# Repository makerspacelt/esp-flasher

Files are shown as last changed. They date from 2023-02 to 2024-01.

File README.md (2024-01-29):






---
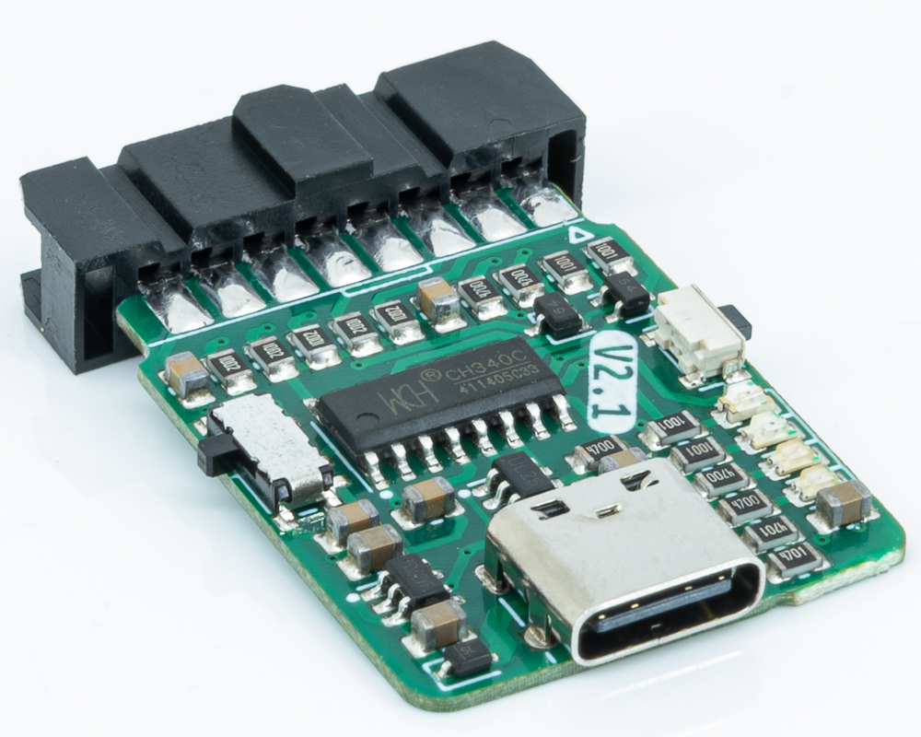
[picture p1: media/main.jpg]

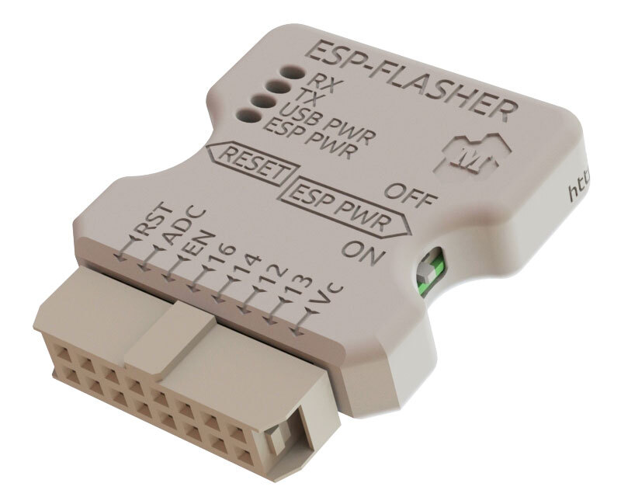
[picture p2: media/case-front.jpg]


This is ESP8266 modular flasher based on CH340 usb uart converter and USB-C port.

* Flashing works with standard `esptool`
* Device can reset ESP automatically
* Device can enter into ESP flashing mode automatically

Support this open-source project - buy your fully assembled and tested flasher [here](http://esp-flasher.makerspace.lt/shop)

For programming and debugging without any onboard provisions in-place use one of these interfaces:

* [ESP-12F interface module](http://esp-12f.makerspace.lt/repo)
* [ESP-01 interface module](http://esp-01.makerspace.lt/repo)

Dev NOTE: before commit, run `./kibot.sh` to regenerate documentation, bom, gerbers and other assets.

* [schematics.pdf](gen/schematics.pdf)
* [pcb.pdf with dimensions](gen/pcb.pdf)
* [ibom.html](gen/single/ibom.html)

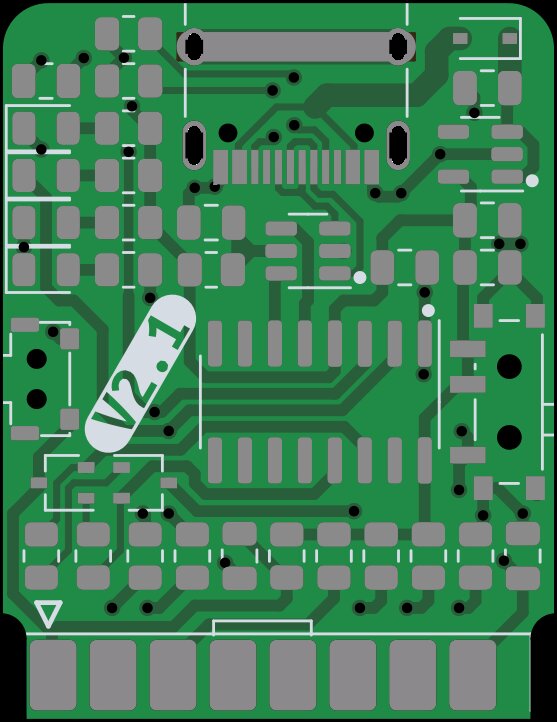
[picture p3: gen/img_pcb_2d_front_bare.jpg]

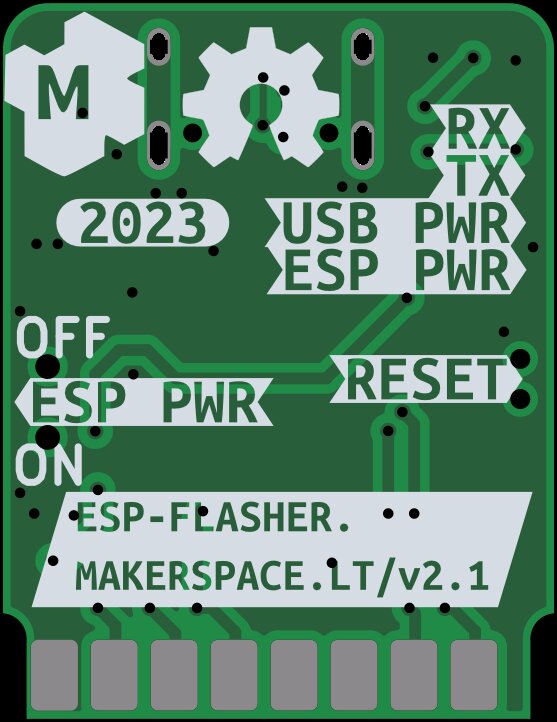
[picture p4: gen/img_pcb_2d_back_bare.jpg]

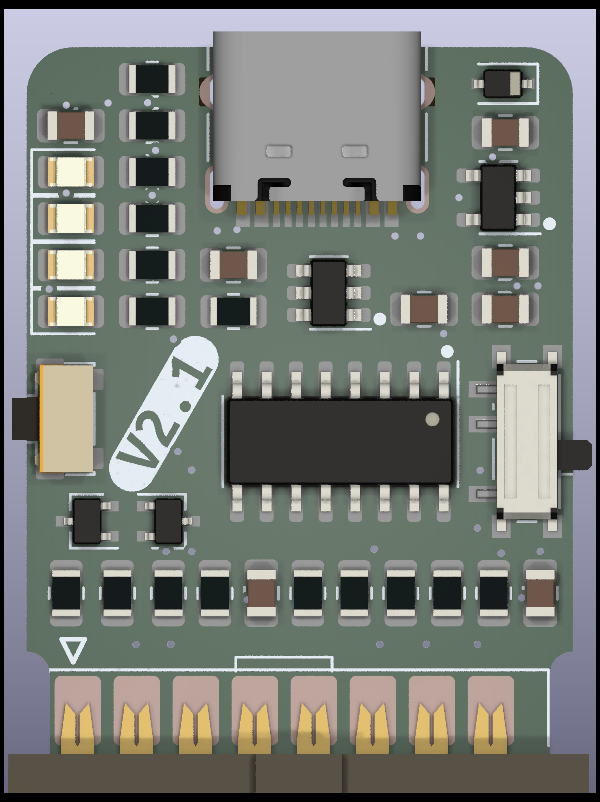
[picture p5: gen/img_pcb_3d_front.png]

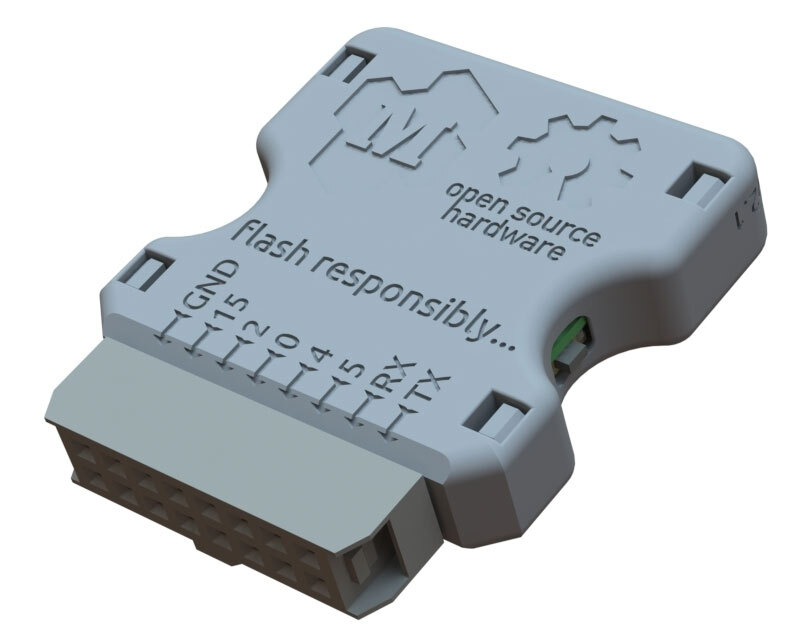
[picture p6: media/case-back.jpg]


---

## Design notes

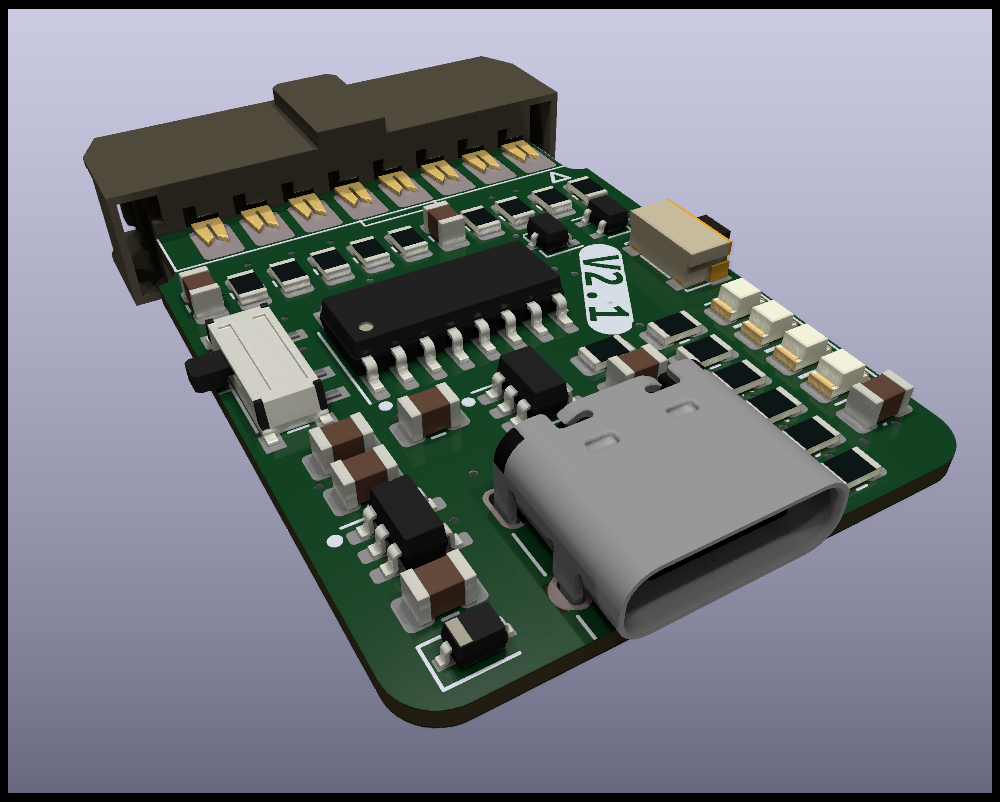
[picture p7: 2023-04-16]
gen/img_pcb_3d_main.png

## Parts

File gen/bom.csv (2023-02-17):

Row | Description | Part | References | Value | Footprint | Quantity Per PCB | Status | Datasheet | jlc-part-type | lcsc# | mpn
1 | Unpolarized capacitor | C | C1,C3,C5,C7,C8 | 100n | C_0805_2012Metric | 5 |  | ~ | B | C28233
2 | Unpolarized capacitor | C | C2,C4,C6 | 10u | C_0805_2012Metric | 3 |  | ~ | B | C15850
3 | Schottky diode | D_Schottky | D1 | B5819WS | D_SOD-323 | 1 |  | https://datasheet.lcsc.com/lcsc/1811011616_Shandong-Jingdao-Microelectronics-B5819WS_C169530.pdf | E | C169530 | B5819WS
4 | Generic connector, double row, 02x08, odd/even pin numbering scheme (row 1 odd numbers, row 2 even numbers), script generated (kicad-library-utils/schlib/autogen/connector/) | Conn_02x08_Odd_Even | J2 | IDC EDGE 2x8 | IDC-Female_2x08_P2.54mm_Edge | 1 |  | ~ | - | C601927
5 | USB 2.0-only Type-C Receptacle connector | USB_C_Receptacle_USB2.0 | J1 | TYPE-C-31-M-12 | USB_C_Receptacle_HRO_TYPE-C-31-M-12 | 1 |  | https://datasheet.lcsc.com/lcsc/2205251630_Korean-Hroparts-Elec-TYPE-C-31-M-12_C165948.pdf | E | C165948 | TYPE-C-31-M-12
6 | Generic connector, single row, 01x01, script generated (kicad-library-utils/schlib/autogen/connector/) | Conn_01x01 | J3 | matching connector for BOM |  | 1 |  | ~ | E | C3406
7 | Light emitting diode | LED | LED4 | ESP-red | LED_0805_2012Metric | 1 |  | https://datasheet.lcsc.com/lcsc/1806151820_Hubei-KENTO-Elec-C2297_C2297.pdf | B | C84256
8 | Light emitting diode | LED | LED1 | PWR-yellow | LED_0805_2012Metric | 1 |  | https://datasheet.lcsc.com/lcsc/1806151820_Hubei-KENTO-Elec-C2297_C2297.pdf | E | C779458
9 | Light emitting diode | LED | LED3 | RX-green | LED_0805_2012Metric | 1 |  | https://datasheet.lcsc.com/lcsc/1806151820_Hubei-KENTO-Elec-C2297_C2297.pdf | E | C965815
10 | Light emitting diode | LED | LED2 | TX-blue | LED_0805_2012Metric | 1 |  | https://datasheet.lcsc.com/lcsc/1806151820_Hubei-KENTO-Elec-C2297_C2297.pdf | E | C965817
11 | NPN transistor, base/emitter/collector | Q_NPN_BEC | Q1,Q2 | DTC114YUA | SOT-323_SC-70 | 2 |  | https://datasheet.lcsc.com/lcsc/1809212227_Changjiang-Electronics-Tech-CJ-DTC114YUA_C13490.pdf | E | C13490 | DTC114YUA
12 | Resistor | R | R7,R9,R10,R14,R15 | 470 | R_0805_2012Metric | 5 |  | ~ | B | C17710
13 | Resistor | R | R8,R11,R12,R13 | 1k | R_0805_2012Metric | 4 |  | ~ | B | C17513
14 | Resistor | R | R5,R6 | 4k7 | R_0805_2012Metric | 2 |  | ~ | B | C17673
15 | Resistor | R | R1,R2,R3,R4,R16 | 10k | R_0805_2012Metric | 5 |  | ~ | B | C17414
16 | Switch, single pole double throw | SW_SPDT | SW2 | ESP Power | SW_SPDT_PCM12 | 1 |  | https://datasheet.lcsc.com/lcsc/1808041445_ALPSALPINE-SSSS811101_C109335.pdf | E | C109335 | SSSS811101
17 | Single Pole Single Throw (SPST) switch | SW_SPST | SW1 | RESET | 1TS003B-2400-3500A-CT | 1 |  | https://datasheet.lcsc.com/lcsc/1811070920_HYP--Hongyuan-Precision-1TS003B-2400-3500A-CT_C319398.pdf | E | C319398 | 1TS003B-2400-3500A-CT
18 | USB serial converter, UART, SOIC-16 | CH340C | U3 | CH340C | SOIC-16_3.9x9.9mm_P1.27mm | 1 |  | https://datasheet.lcsc.com/szlcsc/Jiangsu-Qin-Heng-CH340C_C84681.pdf | E | C84681 | CH340C
19 | 150mA 16V Low-noise Low-dropout Regulator With Shutdown, 3.3V output voltage, SOT-23-5 | LP2985-3.3 | U2 | ME6211C33M5G-N | SOT-23-5 | 1 |  | https://datasheet.lcsc.com/lcsc/1811131510_MICRONE-Nanjing-Micro-One-Elec-ME6211C33M5G-N_C82942.pdf | E | C82942 | ME6211C33M5G-N
20 | Very low capacitance ESD protection diode, 2 data-line, SOT-23-6 | USBLC6-2SC6 | U1 | USBLC6-2SC6 | SOT-23-6 | 1 |  | https://datasheet.lcsc.com/lcsc/2211151800_HXY-MOSFET-USBLC6-2SC6_C5261088.pdf | E | C5261088 | USBLC6-2SC6

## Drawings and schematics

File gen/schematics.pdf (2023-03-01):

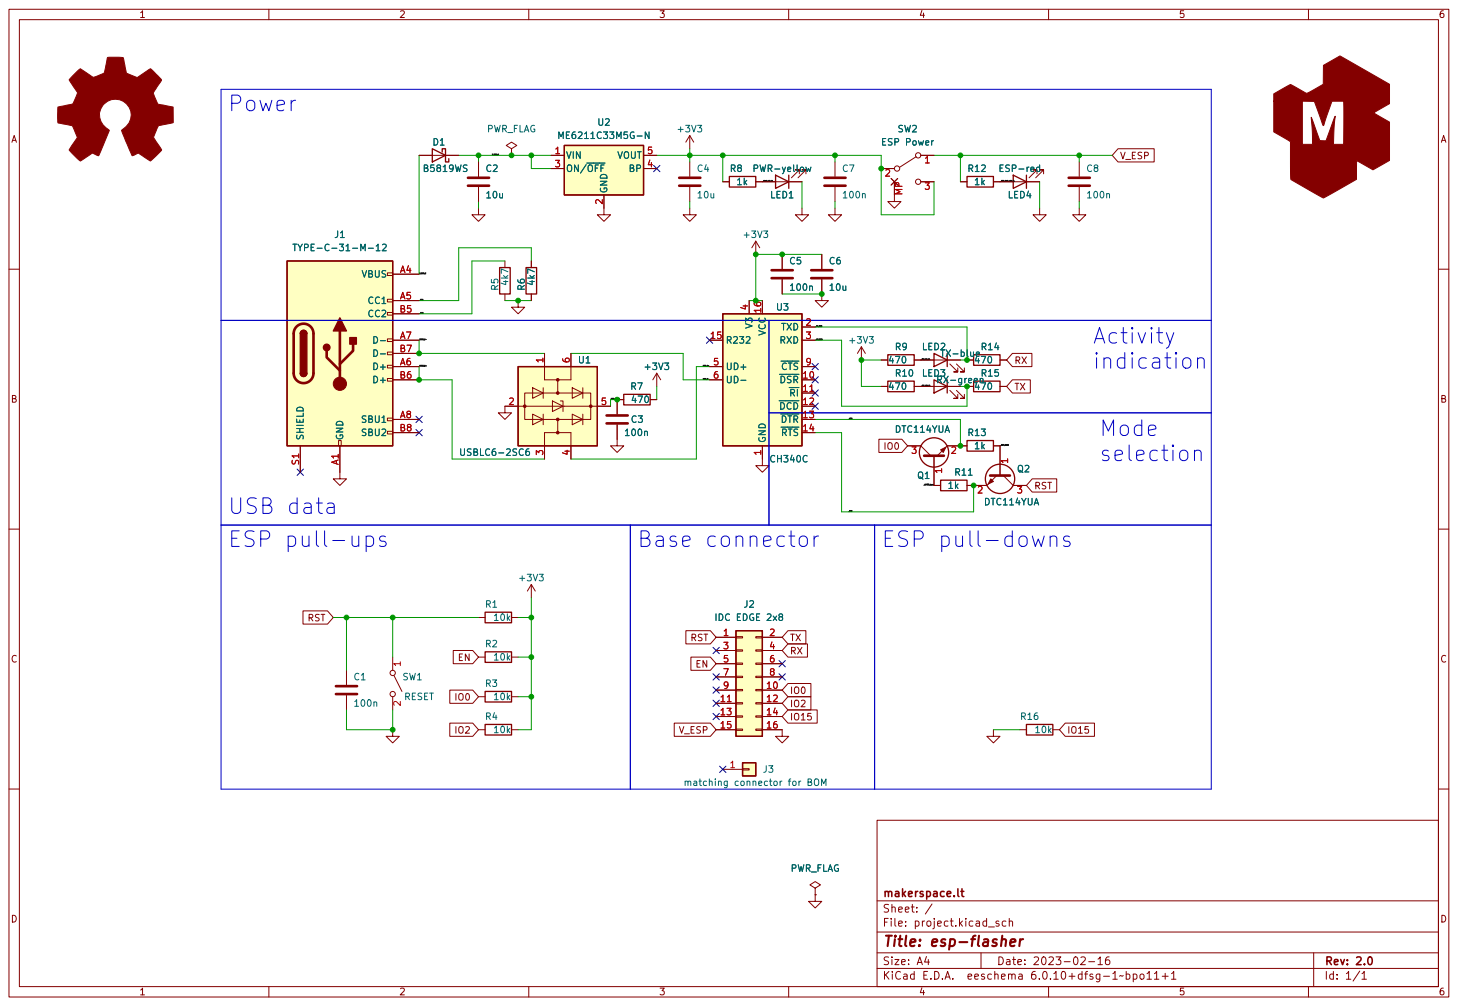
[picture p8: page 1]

2 ON/~{OFF} 3 BP 4 VOUT 5 U2 ME6211C33M5G-N R54k7 GND A1 VBUS A4 CC1 A5 D+ A6 D- A7 SBU1 A8 CC2 B5 D+ B6 D- B7 SBU2 B8 SHIELD S1

2 ON/~{OFF} 3 BP 4 VOUT 5 C2

1 ~{DSR}10 ~{RI}11 ~{DCD}12 ~{DTR}13 ~{RTS}14 R232 15 VCC 16 TXD 2 RXD 3 V3

J3 matching connector for BOM

File: project.kicad_sch Sheet: / makerspace.lt

Id: 1/1 Title: esp-flasher

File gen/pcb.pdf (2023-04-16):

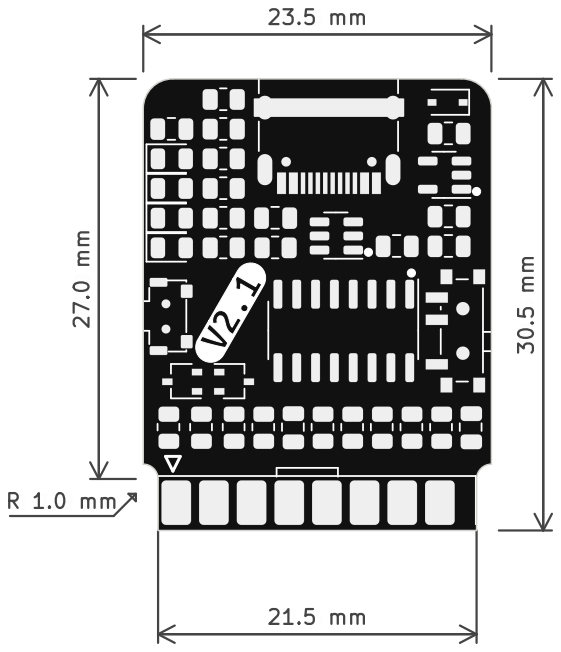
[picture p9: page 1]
mm²⁷.0 mm

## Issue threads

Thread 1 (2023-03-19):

v2.0 slight pins misalignment on USB-C footprint

dariuskt, 2023-03-19:

Closed 2023-03-19.

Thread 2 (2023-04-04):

SW2 (esp pwr) switch missing on/off labels

dariuskt, 2023-04-04:

Closed 2023-04-06.

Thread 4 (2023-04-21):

Add labels for pinouts

dariuskasiulevicius, 2023-04-21:
If I want to connect my custom ESP I need double check each time which pin is what.

dariuskt, 2024-01-29:
solved by providing an enclosure with pinout markings. see commit 4c7da5d

Closed 2024-01-29.

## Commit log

2023-02-16 adding usb-uart adapter v2.0
    [_.kicad_pcb, _.kicad_sch]
2023-02-16 refactoring project files
    [project.kicad_pcb, project.kicad_sch]
2023-02-16 adding kibot and generatables
    [bom.csv, bom_lcsc.csv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]
2023-02-16 adding mating connector to bom
    [bom.csv, bom_lcsc.csv, project.kicad_pcb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]
2023-02-17 refactoring kibot generatables
    [bom.csv, positions.csv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]
2023-02-17 making leds colorful
    [bom.csv, bom_lcsc.csv, project.kicad_pcb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]
2023-02-18 small fixes on connectors models and placement
    [positions.csv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]
2023-02-18 fixing sw1 footprint rotation
    [positions.csv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]
2023-02-18 better marking pin1 direction for ICs
    [project.kicad_pcb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]
2023-02-21 fixing fotprints positions
    [positions.csv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]
2023-03-01 adding panel and refactoring generatables
    [_bom.csv, bom.csv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]
2023-03-19 fine-tuning USB-C footprint, fixes #1
    [_pos.csv, panel--NPTH_map.gbr, panel--PTH_map.gbr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]
2023-04-06 adding on/off labels for sw2 and bumping up to v2.1, fixes #2
    [_pos.csv, panel--NPTH_map.gbr, panel--PTH_map.gbr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]
2023-04-06 adding cutouts for mounting, fixes #3
    [_pos.csv, panel--NPTH_map.gbr, panel--PTH_map.gbr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]
2023-04-16 adding more space for case mounting
    [_bom.csv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]
2023-05-12 adding real device photo
2023-05-26 STEP files of case added.
2024-01-29 adding enclosure images
2024-01-29 adding enclosure images to readme
